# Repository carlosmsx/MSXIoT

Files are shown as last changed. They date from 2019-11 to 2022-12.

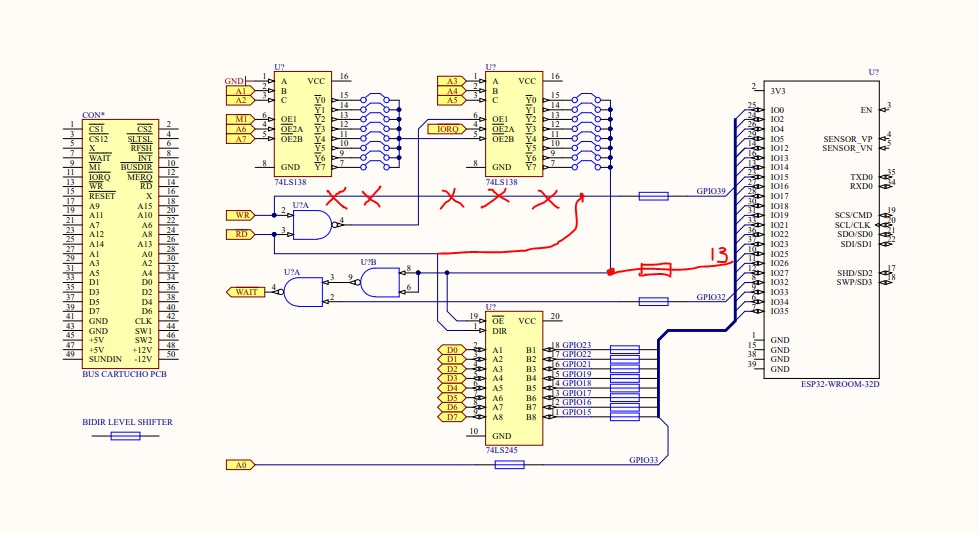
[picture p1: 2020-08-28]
doc/schema.jpg

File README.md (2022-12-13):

# MSX IoT

## Internet de las cosas para MSX
Si estás en este sitio probablemente ya sabes lo que es un MSX.
Pero, has oído hablar de Internet de las cosas (Internet of Things)?
Te presento MSX IoT.

Es un cartucho para MSX que permite IoT y algunos extras muy interesantes:

* Conectarse a redes WiFi
* Conectarse a dispositivos BT
* Conectarse a dispositivos seriales (TTL)
* Audio
* Disco en la nube
* Unidades de red

Una vez conectado a una red WiFi, las posibilidades son muchas. Por ejemplo, es posible comandar dispositivos a través de internet, o bien saber el estado de los mismos.

A nivel de hardware, MSX IoT consta de una ROM, un decodificador de direcciones y un módulo ESP32.

Cada vez que el Z80 accede para lectura o escritura a un puerto designado en el decodificador, se genera una señal WAIT hacia el Z80 y paralelamente se lanza una interrupción en el ESP32. Esto permite que en el microcontrolador se compruebe si la interrupción se debe a una operación de entrada o salida. Con esto el ESP32 puede leer bytes enviados por el Z80, o bien enviarlos a solicitud del mismo. Es decir, el microcontrolador trabaja en modo esclavo. De esta manera es posible establecer intercambio de datos controlados desde el Z80. 

## Otras posibles habilidades del cartucho

### Cloud disk
Para esto es necesario implementar una unidad de disco que permita acceder a un repositorio en la nube. Sería ideal si se pudiese conectar a por ejemplo google drive. 
Mapear una unidad de red a una carpeta compartida de windows o linux.
### Audio
El ESP32 tiene la posibilidad de generar audio a través de dos salidas que poseen un DAC. Sabiendo esto, el cartucho tiene previsto evolucionar sobre este punto de manera de conectar estas salidas a la entrada de audio de MSX. En teoría sería posible generar sonidos tan complejos como la programación del ESP32 lo permita.
### RS232 TTL
Se ha dejado disponible una UART en el cartucho de manera que el cartucho sirva como una interfaz serie. 
Sería necesario implementar las extensiones BASIC correspondientes
- CALL COMBREAK
- CALL COMDTR
- CALL COM GOSUB
- CALL COMHELP
- CALL COMINI
- CALL COMOFF
- CALL COMON
- CALL COMSTAT
- CALL COMSTOP
- CALL COMTERM

© Carlos Escobar 2019

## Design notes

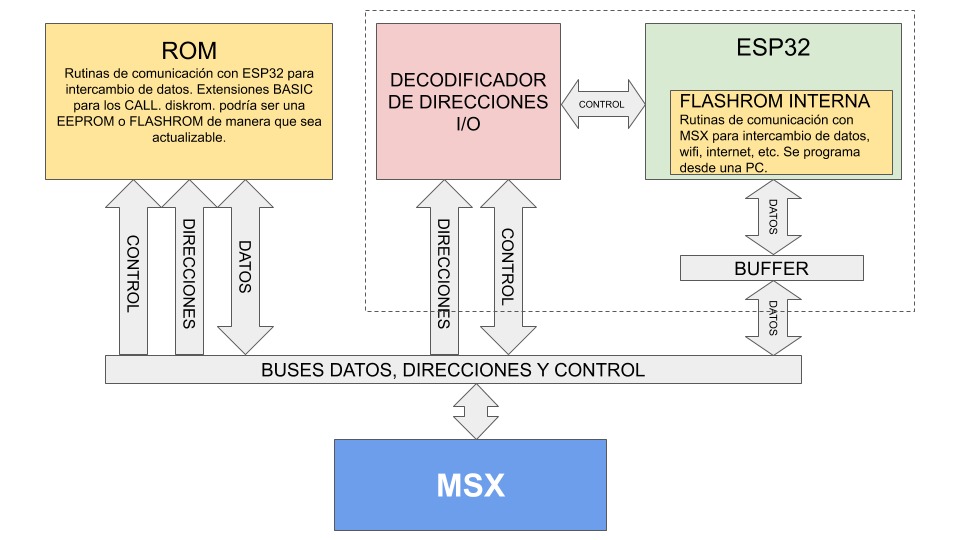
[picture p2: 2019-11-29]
doc/general.jpeg

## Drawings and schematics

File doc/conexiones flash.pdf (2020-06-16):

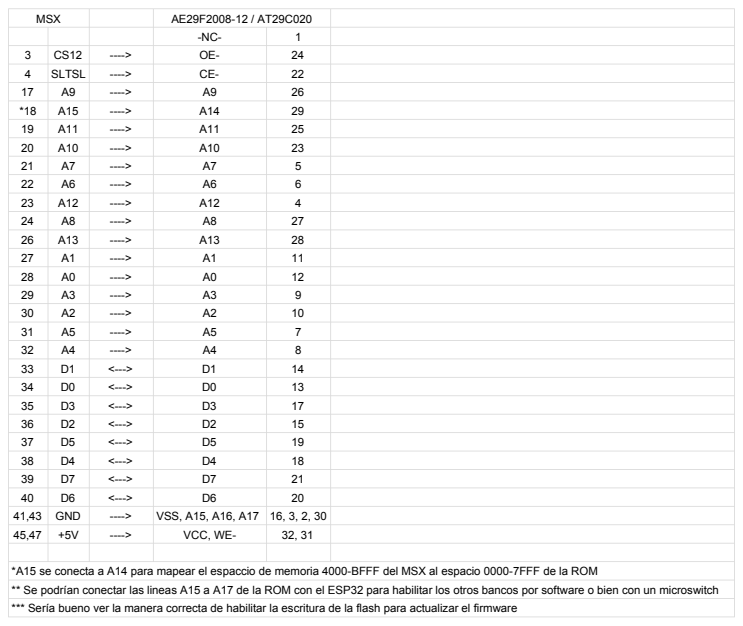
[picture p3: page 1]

*A15 se conecta a A14 para mapear el espaccio de memoria 4000-BFFF del MSX al espacio 0000-7FFF de la ROM
** Se podrían conectar las lineas A15 a A17 de la ROM con el ESP32 para habilitar los otros bancos por software o bien con un microswitch
*** Sería bueno ver la manera correcta de habilitar la escritura de la flash para actualizar el firmware

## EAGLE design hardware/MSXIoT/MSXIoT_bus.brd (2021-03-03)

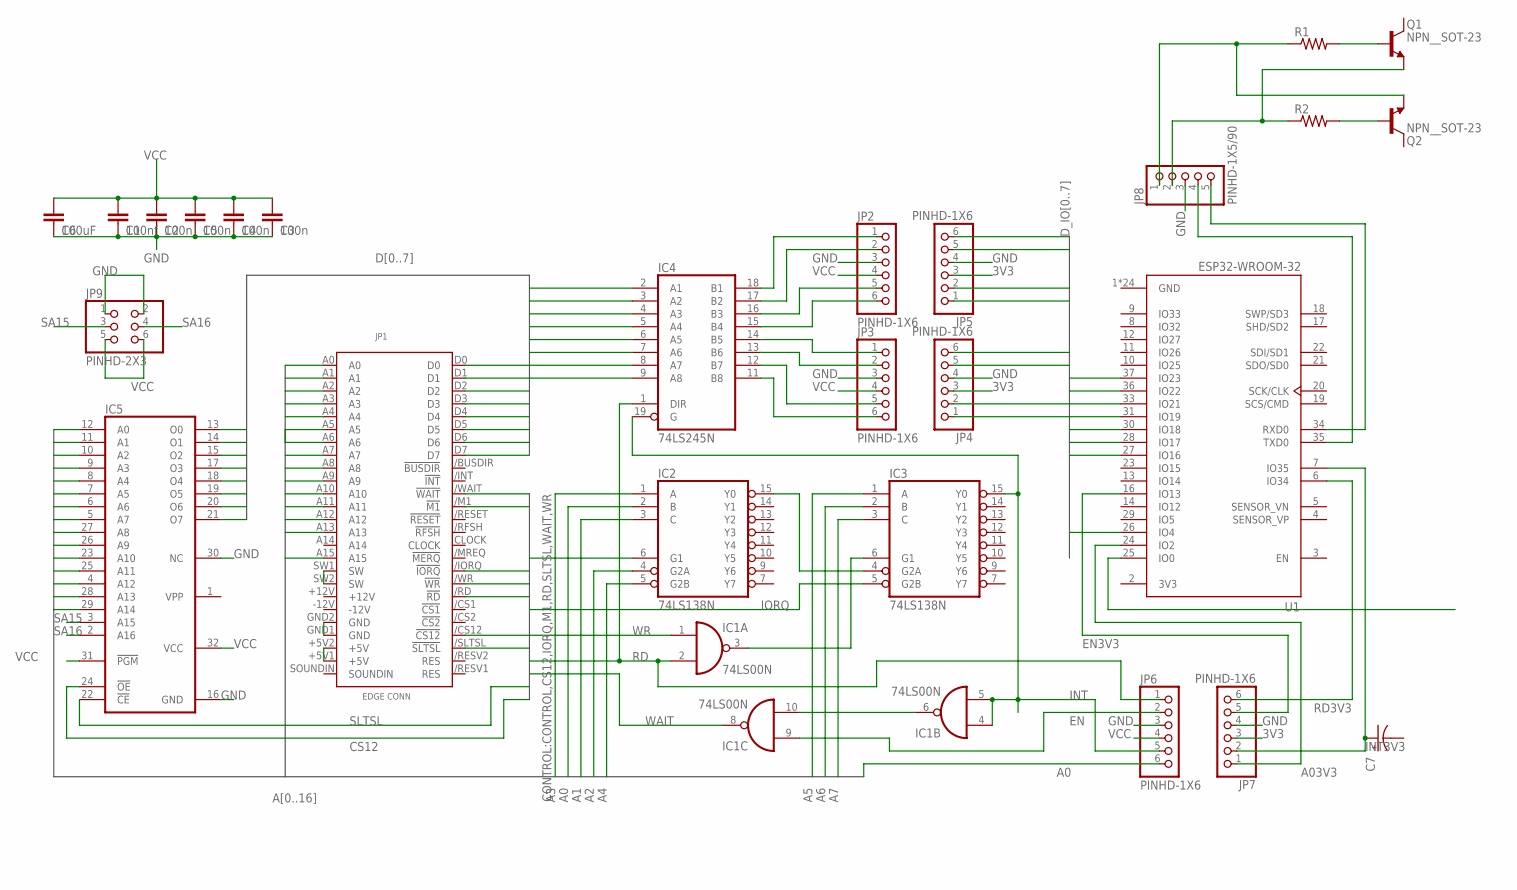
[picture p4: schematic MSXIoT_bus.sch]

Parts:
C1: 100nf; C2.5-2
C2, C3, C4, C5: 100n; C2.5-3
C6: 100uF; C2.5-6
C7: CPOL-US153CLV-0505; 153CLV-0505
IC1: 74LS00N; DIL14
IC2, IC3: 74LS138N; DIL16
IC4: 74LS245N; DIL20
IC5: 27C1001A; DIL32
JP1: MSXCART
JP2, JP3, JP4, JP5, JP6, JP7: PINHD-1X6; 1X06
JP8: PINHD-1X5/90; 1X05/90
JP9: PINHD-2X3; 2X03
Q1, Q2: NPN__SOT-23; SOT95P237X112-3N
R1, R2: R-US_0204/5; 0204/5
U1: ESP32-WROOM-32; MODULE_ESP32-WROOM-32

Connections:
3V3: JP4.3, JP5.3, JP7.3, U1.2 (3V3)
A0: IC2.2 (B), IC5.12 (A0), JP1.A0, JP6.6
A1: IC2.3 (C), IC5.11 (A1), JP1.A1
A2: IC2.4 (G2A), IC5.10 (A2), JP1.A2
A3: IC2.1 (A), IC5.9 (A3), JP1.A3
A03V3: JP7.1, U1.24 (IO2)
A4: IC2.5 (G2B), IC5.8 (A4), JP1.A4
A5: IC3.1 (A), IC5.7 (A5), JP1.A5
A6: IC3.2 (B), IC5.6 (A6), JP1.A6
A7: IC3.3 (C), IC5.5 (A7), JP1.A7
A8: IC5.27 (A8), JP1.A8
A9: IC5.26 (A9), JP1.A9
A10: IC5.23 (A10), JP1.A10
A11: IC5.25 (A11), JP1.A11
A12: IC5.4 (A12), JP1.A12
A13: IC5.28 (A13), JP1.A13
A14: IC5.29 (A14), JP1.A15
CS12: IC5.24 (!OE), JP1./CS12 (!CS12)
D0: IC4.2 (A1), IC5.13 (O0), JP1.D0
D1: IC4.3 (A2), IC5.14 (O1), JP1.D1
D2: IC4.4 (A3), IC5.15 (O2), JP1.D2
D3: IC4.5 (A4), IC5.17 (O3), JP1.D3
D4: IC4.6 (A5), IC5.18 (O4), JP1.D4
D5: IC4.7 (A6), IC5.19 (O5), JP1.D5
D6: IC4.8 (A7), IC5.20 (O6), JP1.D6
D7: IC4.9 (A8), IC5.21 (O7), JP1.D7
D_IO0: JP5.6, U1.37 (IO23)
D_IO1: JP5.5, U1.36 (IO22)
D_IO2: JP5.2, U1.33 (IO21)
D_IO3: JP5.1, U1.31 (IO19)
D_IO4: JP4.6, U1.30 (IO18)
D_IO5: JP4.5, U1.28 (IO17)
D_IO6: JP4.2, U1.27 (IO16)
D_IO7: JP4.1, U1.26 (IO4)
EN: IC1.9 (I0), JP6.2
EN3V3: JP7.5, U1.16 (IO13)
GND: C1.2, C2.2, C3.2, C4.2, C5.2, C6.2, IC1.7 (GND), IC2.8 (GND), IC3.8 (GND), IC4.10 (GND), IC5.16 (GND), IC5.30 (NC), JP1.GND1 (GND), JP1.GND2 (GND), JP2.3, JP3.3, JP4.4, JP5.4, JP6.3, JP7.4, JP8.3, JP9.1, JP9.2, U1.1 (GND), U1.15 (GND), U1.38 (GND), U1.39_1 (GND), U1.39_2 (GND), U1.39_3 (GND), U1.39_4 (GND), U1.39_5 (GND), U1.39_6 (GND), U1.39_7 (GND), U1.39_8 (GND), U1.39_9 (GND), U1.39_10 (GND), U1.39_11 (GND), U1.39_12 (GND), U1.39_13 (GND), U1.39_14 (GND), U1.39_15 (GND), U1.39_16 (GND), U1.39_17 (GND), U1.39_18 (GND), U1.39_19 (GND), U1.39_20 (GND), U1.39_21 (GND)
INT: IC1.4 (I0), IC1.5 (I1), IC3.15 (Y0), IC4.19 (G), JP6.5
INT3V3: C7.+, JP7.2, U1.7 (IO35)
IORQ: IC3.5 (G2B), JP1./IORQ (!IORQ)
M1: IC2.6 (G1), JP1./M1 (!M1)
unnamed: IC1.6 (O), IC1.10 (I1)
unnamed: IC4.18 (B1), JP2.1
unnamed: IC2.15 (Y0), IC3.4 (G2A)
unnamed: IC1.3 (O), IC3.6 (G1)
unnamed: IC4.17 (B2), JP2.2
unnamed: IC4.16 (B3), JP2.5
unnamed: IC4.15 (B4), JP2.6
unnamed: IC4.14 (B5), JP3.1
unnamed: IC4.13 (B6), JP3.2
unnamed: IC4.12 (B7), JP3.5
unnamed: IC4.11 (B8), JP3.6
unnamed: JP1.SW1 (SW), JP1.SW2 (SW)
unnamed: JP8.4, U1.35 (TXD0)
unnamed: JP8.5, U1.34 (RXD0)
unnamed: JP8.1, Q2.1 (E), R1.1
unnamed: Q1.2 (B), R1.2
unnamed: Q2.2 (B), R2.2
unnamed: JP8.2, Q1.1 (E), R2.1
RD: IC1.2 (I1), IC4.1 (DIR), JP1./RD (!RD), JP6.1
RD3V3: JP7.6, U1.6 (IO34)
SA15: IC5.3 (A15), JP9.3
SA16: IC5.2 (A16), JP9.4
SLTSL: IC5.22 (!CE), JP1./SLTSL (!SLTSL)
VCC: C1.1, C2.1, C3.1, C4.1, C5.1, C6.1, IC1.14 (VCC), IC2.16 (VCC), IC3.16 (VCC), IC4.20 (VCC), IC5.31 (!PGM), IC5.32 (VCC), JP1.+5V1 (+5V), JP1.+5V2 (+5V), JP2.4, JP3.4, JP6.4, JP9.5, JP9.6
WAIT: IC1.8 (O), JP1./WAIT (!WAIT)
WR: IC1.1 (I0), JP1./WR (!WR)

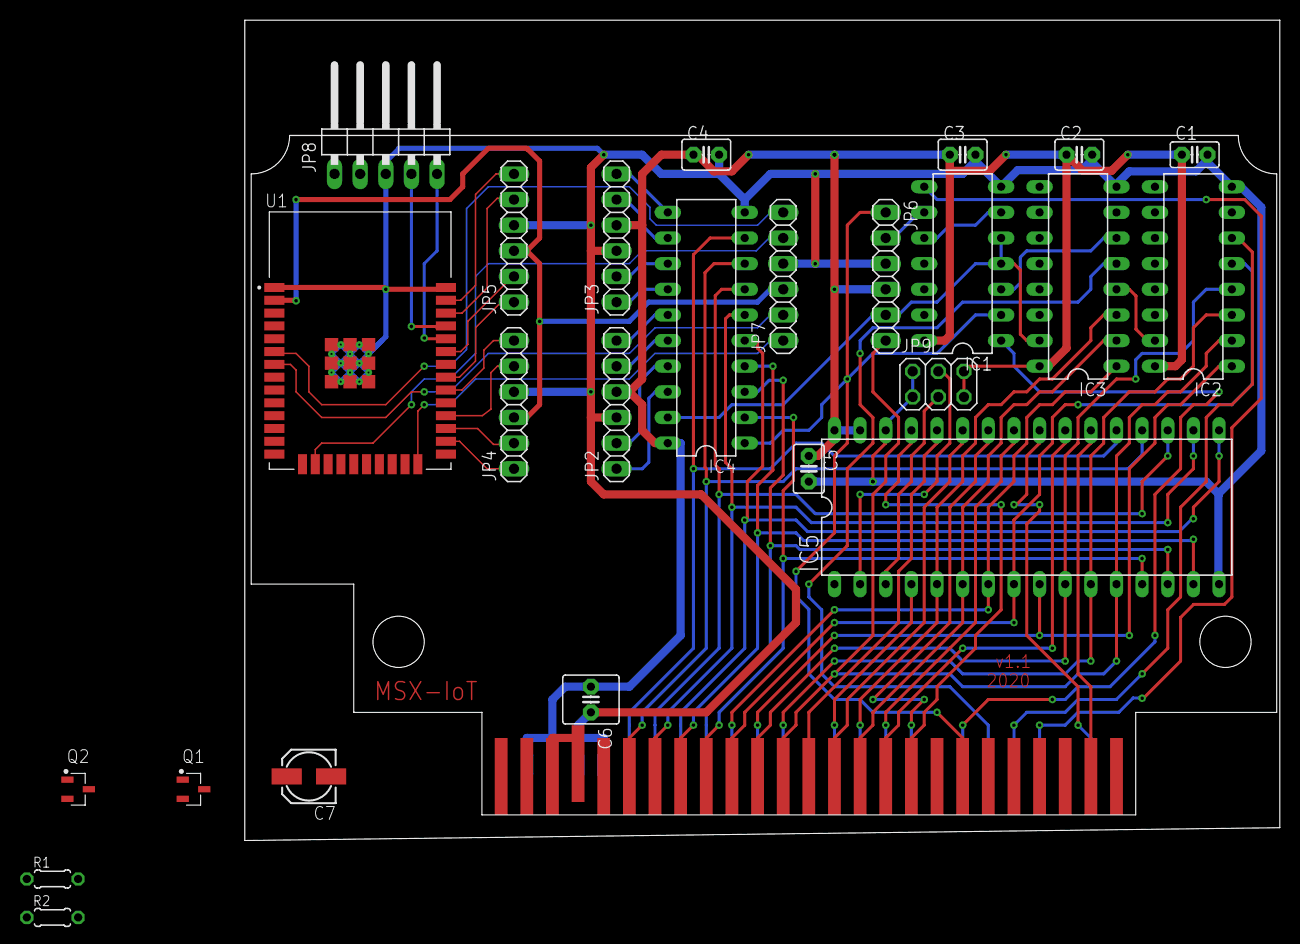
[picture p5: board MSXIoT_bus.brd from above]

Board: 2 copper layers, 102.5 x 81.3 mm, 26 parts (0 on the bottom side), 67 nets.

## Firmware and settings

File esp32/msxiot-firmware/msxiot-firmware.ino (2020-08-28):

/*
 * MSX INTERFACE DECO+ESP32
 * Autor: Carlos Escobar
 * 2019
 * 
 * Placa: ESP32 Dev Module
 * Partition Scheme: Huge APP (3MB No OTA/1MB SPIFFS)
 */
 
#include "BluetoothSerial.h" 
#include <WiFi.h>
#include <HTTPClient.h>
#include <string.h>
#include "SPIFFS.h"
#include "GDrive.h"

#define PIN_WAIT_EN 32
#define PIN_WAIT_ST 13
#define PIN_RD 39
#define PIN_A0 33
#define DATA_PINS {15,16,17,18,19,21,22,23} 

//32768+2
#define BUFSIZE 0x8002

#define CMD_NULL 0x00
#define CMD_SENDSTR 0x01
#define CMD_WLIST 0x10
#define CMD_WCLIST 0x11
#define CMD_WNET 0x12
#define CMD_WPASS 0x13
#define CMD_WCONN 0x14
#define CMD_WDISCON 0x15
#define CMD_WSTAT 0x16
#define CMD_WLOAD 0x17
#define CMD_WBLOAD 0x18
#define CMD_TCPSVR 0x19
#define CMD_TCPSEND 0x1A

#define CMD_FNAME 0x60
#define CMD_FSAVE 0x61
#define CMD_FLOAD 0x62
#define CMD_FFILES 0x63
#define CMD_LOADROM 0x64

#define CMD_CLOUDROM 0x70

#define CMD_GD_LST  0x80
#define CMD_GD_UPL  0x81
#define CMD_GD_DWL  0x82

static volatile uint16_t st_idx;
static volatile uint16_t st_size; //mantiene el tamaño del dato en el buffer
static volatile uint8_t st_cmd;   //indica el comando ejecutado

static volatile uint8_t st_status;
/*
  st_status: variable que indica el estado de la última operación
    7 6 5 4 3 2 1 0
    | | | | | | | \__ 
    | | | | | | \____
    | | | | | \______
    | | | | \________
    | | | \__________
    | | \____________
    | \______________ en alto indica que hay datos disponibles para leer desde el BUFFER (DATA_READY)
    \________________ en alto indica que la interfaz está ocupada (BUSY)
 */

#define BUSY 0x80
#define DATA_READY 0x40

char *st_buffer; //dynamically better
char *st_ssid = NULL;
char *st_password = NULL;
char st_server[64];
char st_file_name[64];
static volatile uint16_t st_server_port;

DRAM_ATTR const byte dmap[] = DATA_PINS;

/* Stores the handle of the task that will be notified when the
transmission is complete. */
static TaskHandle_t xTaskToNotify = NULL;

BluetoothSerial ESP_BT; //Object for Bluetooth

void IRAM_ATTR decoInt();
void IRAM_ATTR decoInt_old();

void IRAM_ATTR TaskISR( void * parameter) 
{
  uint32_t ulNotificationValue;

  while (true)
  {
    //waits for ISR notification
    ulNotificationValue = ulTaskNotifyTake( pdTRUE, portMAX_DELAY  );
    //st_counter2++;  
    if( ulNotificationValue == 1 )
    {
        /* The transmission ended as expected. */
        decoInt_old();
    }
  }
}

void setup() {
  Serial.begin(115200);
  
  if (!SPIFFS.begin(true)) {
    Serial.println("An Error has occurred while mounting SPIFFS");
    return;
  }

  /*
  File root = SPIFFS.open("/");
  File file = root.openNextFile();
  while(file){
      Serial.print("FILE: ");
      Serial.println(file.name());
      file = root.openNextFile();
  }
  file.close();
  */
  
  st_buffer = new char[BUFSIZE+2];

  ESP_BT.begin("MSX-IoT BT"); //Name of your Bluetooth Signal
  
  pinMode(PIN_WAIT_ST, INPUT_PULLUP);
  pinMode(PIN_RD, INPUT_PULLUP);
  pinMode(PIN_WAIT_EN, OUTPUT);
  pinMode(PIN_A0, INPUT_PULLUP);

  for (int i=0; i<8; i++)
    pinMode(dmap[i], INPUT);

  while (digitalRead(PIN_WAIT_ST)==LOW)
    digitalWrite(PIN_WAIT_EN, HIGH); //LOW);
  digitalWrite(PIN_WAIT_EN, LOW); //HIGH);

  String s = "MSX IoT 2019 corriendo en core "+String(xPortGetCoreID())+"\n";
  Serial.print(s);

  xTaskCreate(TaskISR, "decoInt", 1000, NULL, 10, &xTaskToNotify);
    
  attachInterrupt(digitalPinToInterrupt(PIN_WAIT_ST), decoInt, FALLING);
}

void IRAM_ATTR readData(uint8_t data)
{
  if (st_size<BUFSIZE) //<sizeof(_buffer))
  {
    st_buffer[st_size++]=data;
  }
  else
    st_status=0x01;
}

void IRAM_ATTR readCommand(uint8_t cmd)
{
  if (st_status & BUSY) 
    return;

  switch(cmd){
    case CMD_SENDSTR:
      st_idx = 0;
      st_size=0;
      st_status = DATA_READY;
      st_cmd = cmd;
      break;
    case CMD_WLIST:
    case CMD_WCLIST:
    case CMD_WCONN:
    case CMD_WDISCON:
    case CMD_WSTAT:
    case CMD_WNET: 
    case CMD_WPASS:
    case CMD_WLOAD:
    case CMD_WBLOAD:
    case CMD_TCPSVR:
    case CMD_TCPSEND:
    case CMD_FSAVE:
    case CMD_FLOAD:
    case CMD_FFILES:
    case CMD_FNAME:
    case CMD_LOADROM:
    case CMD_CLOUDROM:
    case CMD_GD_UPL:
      st_status = BUSY;
      st_cmd = cmd;
      break;
  }
}

void IRAM_ATTR receiveByte(int A0)
{
  uint8_t data=0;
  uint8_t bit=1;
  for (int i=0; i<8; i++)
  {
    if (digitalRead(dmap[i])==HIGH)
      data|=bit;
    bit=bit<<1; 
  }

  if (A0==0) 
    readData(data);
  else 
    readCommand(data);  

  while (digitalRead(PIN_WAIT_ST)==LOW)
    digitalWrite(PIN_WAIT_EN, HIGH); 
  digitalWrite(PIN_WAIT_EN, LOW);
}

uint8_t IRAM_ATTR writeData()
{
  if (st_status==DATA_READY && st_idx<st_size)
  {
    return st_buffer[st_idx++];
  }
  st_status=0;
  return 0;
}

void IRAM_ATTR dispatchByte(int A0)
{    
  uint8_t data=0;
  if (A0==0)
  {
    data=writeData();
  }
  else
  {
    data=st_status;
  }
  
  uint8_t bit=1;
  for (int i=0; i<8; i++)
  {
    pinMode(dmap[i], OUTPUT);
    digitalWrite(dmap[i], data&bit?HIGH:LOW);
    bit=bit<<1; 
  }

  delayMicroseconds(5);

  digitalWrite(PIN_WAIT_EN, HIGH);
  while (digitalRead(PIN_WAIT_ST)==LOW);
    digitalWrite(PIN_WAIT_EN, HIGH); 

  delayMicroseconds(5);

  //for (int i=0; i<8; i++)
  //  pinMode(dmap[i], INPUT);

  digitalWrite(PIN_WAIT_EN, LOW); 
}

void IRAM_ATTR decoInt_old()
{
  //st_counter3++;  
  int A0 = digitalRead(PIN_A0);
  int RD = digitalRead(PIN_RD);
  
  if (RD==HIGH) 
    receiveByte(A0);
  else
    dispatchByte(A0);
}

void IRAM_ATTR decoInt()
{
  //st_counter++;  
  BaseType_t xHigherPriorityTaskWoken = pdFALSE;
  vTaskNotifyGiveFromISR( xTaskToNotify, &xHigherPriorityTaskWoken );
  if (xHigherPriorityTaskWoken) 
    portYIELD_FROM_ISR( );
}

void getStrFromBuffer(char **s)
{
  char *p = *s;
  
  if (p != NULL)
    delete p;

  p = new char[st_size+1];
    
  for (st_idx=0; st_idx<st_size; st_idx++)
    p[st_idx] = st_buffer[st_idx];
  p[st_idx]='\0';

  Serial.println(p);
  *s=p;
}

void loop() {
  if (Serial.available()>0)
  {
    String s=Serial.readString();
    if (s=="dump")
    {
      for (uint16_t i=0; i<st_size; i++)
      {
        String s_hexa="";
        String s="";
        for(int j=0; j<32; j++, i++)
        {
          s_hexa=s_hexa+String(st_buffer[i],HEX)+" ";
          s=s+(st_buffer[i]>=32 && st_buffer[i]<128?String(st_buffer[i]):".");
        }
        Serial.println(s_hexa+s);    
      }
    }
    else
      st_status=(byte)atoi(s.c_str());
  }

  switch(st_cmd)
  {
    case CMD_WLIST:
    case CMD_WCLIST:
      {
        Serial.println("procesando comando "+String(st_cmd, HEX));
        int numSsid = WiFi.scanNetworks();
        
        if (numSsid == -1)
          st_size = sprintf(st_buffer, "WiFi net not found\r\n");
        else
        {
          st_size=0;
          for (int thisNet = 0; thisNet < numSsid; thisNet++) {
            if (st_cmd == CMD_WCLIST) 
              st_size += sprintf(&st_buffer[st_size], "_WNET(\"%s\")\r\n", WiFi.SSID(thisNet).c_str());
            else
              st_size += sprintf(&st_buffer[st_size], "%s\r\n", WiFi.SSID(thisNet).c_str());
          }
        }
        Serial.write((uint8_t*)st_buffer, st_size);
        st_cmd = 0;
        st_idx = 0;
        st_status = DATA_READY;
      }
      break;
    case CMD_WCONN:
      {
        if (st_ssid == NULL && st_password == NULL) 
        {
          st_size = sprintf(st_buffer, "first run _wnet(...) and _wpass(...)\r\n");
        }
        else if (st_ssid == NULL) 
        {
          st_size = sprintf(st_buffer, "first run _wnet(...)\r\n");
        }
        else if (st_password == NULL) 
        {
          st_size = sprintf(st_buffer, "first run _wpass(...)\r\n");
        }
        else
        {
          Serial.println("procesando comando "+String(st_cmd, HEX));
          WiFi.mode(WIFI_STA);
          WiFi.begin(st_ssid, st_password);
         
          //TODO: manejar máximo de reintentos para que no quede infinitamente
          uint8_t i = 0;
          while (WiFi.status() != WL_CONNECTED)
          {
            Serial.print('.');
            delay(500);
         
            if ((++i % 16) == 0)
            {
              Serial.println(F(" still trying to connect"));
            }
          }
          st_size = sprintf(st_buffer, "Connected to \"%s\"\r\nIP: %s\r\n", st_ssid, WiFi.localIP().toString().c_str());
          Serial.write((uint8_t*)st_buffer, st_size);
        }
        st_cmd = 0;
        st_idx = 0;
        st_status = DATA_READY;
      }
      break;
    case CMD_WDISCON:
      {
        WiFi.disconnect();
        st_size = sprintf(st_buffer, "disconnected\r\n");
        Serial.write((uint8_t*)st_buffer, st_size);
        st_cmd = 0;
        st_idx = 0;
        st_status = DATA_READY;
      }
      break;
    case CMD_WSTAT:
      {
        if (WiFi.status()==WL_CONNECTED)
          st_size = sprintf(st_buffer, "Connected to \"%s\"\r\nIP: %s\r\n", st_ssid, WiFi.localIP().toString().c_str());
        else
          st_size = sprintf(st_buffer, "Not connected\r\n");
        Serial.write((uint8_t*)st_buffer, st_size);
        st_cmd = 0;
        st_idx = 0;
        st_status = DATA_READY;
      }
      break;
    case CMD_WNET:
      /*
      for (st_idx=0; st_idx<st_size && st_idx<sizeof(st_ssid)-1; st_idx++)
        st_ssid[st_idx] = st_buffer[st_idx];
      st_ssid[st_idx]='\0';
      */
      getStrFromBuffer(&st_ssid);
      Serial.println("ssid="+String(st_ssid));
      st_cmd = 0;
      st_status=0;
      break;    
    case CMD_WPASS:
      /*
      for (st_idx=0; st_idx<st_size && st_idx<sizeof(st_password)-1; st_idx++)
        st_password[st_idx] = st_buffer[st_idx];
      st_password[st_idx]='\0';
      */
      getStrFromBuffer(&st_password);
      Serial.println("password="+String(st_password));
      st_cmd = 0;
      st_status=0;
      break;    
    case CMD_WLOAD:
      Serial.print("load=");
      for (int i=0; i<st_size; i++)
        Serial.print(String(st_buffer[i]));
      st_cmd = 0;
      st_status=0;
      break;    
    case CMD_WBLOAD:
      Serial.print("bload=");
      for (int i=0; i<st_size; i++)
        Serial.print(String(st_buffer[i]));
      st_cmd = 0;
      st_status=0;
      break;    
    case CMD_TCPSVR:
      st_buffer[st_size]='\0';
      strcpy(st_server, strtok(st_buffer, ":\0"));
      st_server_port=atoi(strtok(NULL, "\0"));
      Serial.println("server="+String(st_server)+":"+String(st_server_port));
      st_cmd = 0;
      st_status=0;
      break;    
    case CMD_TCPSEND:
      {
        WiFiClient client;
        if (client.connect(st_server, st_server_port)) {
          client.write(st_buffer, st_size);
          st_size = sprintf(st_buffer, "Sent Ok\r\n");
        }
        else
        {
          st_size = sprintf(st_buffer, "ERROR\r\n");
        }
        st_cmd = 0;
        st_idx = 0;
        st_status = DATA_READY;
      }
      break;
    case CMD_FNAME:
      for (st_idx=0; st_idx<st_size && st_idx<sizeof(st_file_name)-1; st_idx++)
        st_file_name[st_idx] = st_buffer[st_idx];
      st_file_name[st_idx]='\0';
      Serial.println("st_file_name="+String(st_file_name));
      st_cmd = 0;
      st_status=0;
      break;    
    case CMD_FSAVE:
      {
        Serial.println("FSAVE st_file_name="+String(st_file_name));
        String fname = "/"+String(st_file_name);
        File f = SPIFFS.open(fname.c_str(), "w");
        if (f) {
          f.write((uint8_t*)st_buffer, st_size);
          f.close();
        }
        st_cmd = 0;
        st_status=0;
      }
      break;    
    case CMD_FLOAD:
      {
        for (st_idx=0; st_idx<st_size && st_idx<sizeof(st_file_name)-1; st_idx++)
          st_file_name[st_idx] = st_buffer[st_idx];
        st_file_name[st_idx]='\0';
        Serial.println("FLOAD st_file_name="+String(st_file_name));
        String fname = "/"+String(st_file_name);
        File f = SPIFFS.open(fname.c_str(), "r");
        if (f) {
          st_size=f.size()+2;
          st_buffer[0]=(uint8_t)(st_size & 0xff);
          st_buffer[1]=(uint8_t)(st_size >> 8);
          Serial.println(String(f.size()));
          Serial.println(String(st_size));
          Serial.println(String((int)st_buffer[0]));
          Serial.println(String((int)st_buffer[1]));
          f.read((uint8_t*)(st_buffer+2), f.size());
          f.close();
        }
        st_idx=0;
        st_cmd = 0;
        st_status=DATA_READY;
      }
      break;    
    case CMD_LOADROM:
      {
        for (st_idx=0; st_idx<st_size && st_idx<sizeof(st_file_name)-1; st_idx++)
          st_file_name[st_idx] = st_buffer[st_idx];
        st_file_name[st_idx]='\0';
        //sprintf(st_file_name, "game.rom");
        Serial.println("FROM st_file_name="+String(st_file_name));
        String fname = "/"+String(st_file_name);
        File f = SPIFFS.open(fname.c_str(), "r");
        if (f) {
          st_size=f.size()+2;
          st_buffer[0]=(uint8_t)(st_size & 0xff);
          st_buffer[1]=(uint8_t)(st_size >> 8);
          Serial.println(String(f.size()));
          Serial.println(String(st_size));
          Serial.println(String((int)st_buffer[0]));
          Serial.println(String((int)st_buffer[1]));
          f.read((uint8_t*)(st_buffer+2), f.size());
          f.close();
        }
        st_idx=0;
        st_cmd = 0;
        st_status=DATA_READY;
      }
      break;    
    case CMD_FFILES:
      {
        File root = SPIFFS.open("/");
        File file = root.openNextFile();
        st_size=0;
       
        while(file){
          st_size += sprintf(&st_buffer[st_size], "%-13s\t%6i\r\n", file.name(), file.size());
          file = root.openNextFile();
        }
        file.close();

        Serial.write((uint8_t*)st_buffer, st_size);
        st_cmd = 0;
        st_idx = 0;
        st_status = DATA_READY;
      }
      break;
    case CMD_CLOUDROM:
      {
        //char st_url[128];
        //for (st_idx=0; st_idx<st_size && st_idx<sizeof(st_url)-1; st_idx++)
        //  st_url[st_idx] = st_buffer[st_idx];
        //st_url[st_idx]='\0';
        char *st_url=NULL;
        getStrFromBuffer(&st_url);

        String file_name=String(st_url).substring(String(st_url).lastIndexOf('/'));
        //Serial.println(st_url);
        HTTPClient http;
        File f = SPIFFS.open(file_name, "w");
        if (f) {
          http.begin(st_url);
          int httpCode = http.GET();
          if (httpCode > 0) 
          {
            if (httpCode == HTTP_CODE_OK) 
            {
              http.writeToStream(&f);
              st_size = sprintf(st_buffer, "Downloaded to \"%s\"\r\n", file_name.c_str());
            }
            else if (httpCode == 301) //redireccion
            {
              Serial.println("ups");
              st_size = sprintf(st_buffer, "HTTP GET redirect\r\n", httpCode);
            }
            else
            {
              Serial.printf("[HTTP] GET... failed, error: %s\r\n", http.errorToString(httpCode).c_str());
              st_size = sprintf(st_buffer, "HTTP GET error: %i\r\n", httpCode);
            }          
          } else 
          {
            Serial.printf("[HTTP] GET... failed, error: %s\r\n", http.errorToString(httpCode).c_str());
            st_size = sprintf(st_buffer, "HTTP GET error: %i\r\n", httpCode);
          }
          f.close();
        }
        else
        {
          st_size = sprintf(st_buffer, "Error openning file\r\n");
        }
        http.end();

        delete st_url;
        st_status = DATA_READY;
        st_cmd = 0;
        st_idx = 0;
      }
      break;
    case CMD_GD_UPL:
      {
        char *fileName = NULL;
        getStrFromBuffer(&fileName);

        String file_name= "/" + String(fileName);
        File f = SPIFFS.open(file_name.c_str(), "r");
        if (f) {
          st_size=f.size();
          f.read((uint8_t*)(st_buffer), f.size());
          f.close();
          if (upload(st_buffer, st_size, 10000))
            st_size = sprintf(st_buffer, "Upload Ok\r\n");
          else
            st_size = sprintf(st_buffer, "Upload Error\r\n");
        }
        else
        {
          st_size = sprintf(st_buffer, "Error openning file\r\n");
        }

        delete fileName;
        st_status = DATA_READY;
        st_cmd = 0;
        st_idx = 0;
      }
      break;
    case CMD_SENDSTR:
    case CMD_NULL:
      break;
    default:
      Serial.println("comando desconocido "+String(st_cmd));
  }
}

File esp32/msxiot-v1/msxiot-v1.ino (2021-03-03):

/*
 * MSX INTERFACE DECO+ESP32
 * Autor: Carlos Escobar
 * 2020
 * 
 * Placa: ESP32 Dev Module
 * Partition Scheme: Huge APP (3MB No OTA/1MB SPIFFS)
 */
 
#include "BluetoothSerial.h" 
#include <WiFi.h>
#include <HTTPClient.h>
#include <string.h>
#include "SPIFFS.h"
#include <freertos/FreeRTOS.h>
#include <freertos/task.h>
#include <freertos/task.h>
#include <driver/gpio.h>

#define PIN_WAIT_EN 32
#define PIN_WAIT_ST 13
#define PIN_RD 39
#define PIN_A0 33
#define D0 15
#define D1 16
#define D2 17
#define D3 18
#define D4 19
#define D5 21
#define D6 22
#define D7 23

#define DATA_MODE(x) pinMode(D0, x); pinMode(D1, x); pinMode(D2, x); pinMode(D3, x); pinMode(D4, x); pinMode(D5, x); pinMode(D6, x); pinMode(D7, x)
#define ARM_WAIT digitalWrite(PIN_WAIT_EN, LOW)
#define RELEASE_WAIT digitalWrite(PIN_WAIT_EN, HIGH)

#define READ_FROM_MSX(data) \
  if (digitalRead(D0)==HIGH) data =  0x01;\
  if (digitalRead(D1)==HIGH) data |= 0x02;\
  if (digitalRead(D2)==HIGH) data |= 0x04;\
  if (digitalRead(D3)==HIGH) data |= 0x08;\
  if (digitalRead(D4)==HIGH) data |= 0x10;\
  if (digitalRead(D5)==HIGH) data |= 0x20;\
  if (digitalRead(D6)==HIGH) data |= 0x40;\
  if (digitalRead(D7)==HIGH) data |= 0x80
  
#define WRITE_TO_MSX(data) \
  digitalWrite(D0, data&0x01?HIGH:LOW);\
  digitalWrite(D1, data&0x02?HIGH:LOW);\
  digitalWrite(D2, data&0x04?HIGH:LOW);\
  digitalWrite(D3, data&0x08?HIGH:LOW);\
  digitalWrite(D4, data&0x10?HIGH:LOW);\
  digitalWrite(D5, data&0x20?HIGH:LOW);\
  digitalWrite(D6, data&0x40?HIGH:LOW);\
  digitalWrite(D7, data&0x80?HIGH:LOW)

static uint16_t waitting_for_data = 0;
static uint8_t status_register = 0;
static uint8_t buf[512];

QueueHandle_t r_queue;
File dsk;

/* Stores the handle of the task that will be notified when pin ST change */
static TaskHandle_t xTaskToNotify = NULL;

BluetoothSerial ESP_BT; //Object for Bluetooth

/*
  st_status: variable que indica el estado de la última operación
    7 6 5 4 3 2 1 0
    | | | | | | | \__ 
    | | | | | | \____
    | | | | | \______
    | | | | \________
    | | | \__________
    | | \____________
    | \______________ en alto indica que hay datos disponibles para leer desde el BUFFER (DATA_READY)
    \________________ en alto indica que la interfaz está ocupada (BUSY)
 */

#define BUSY 0x80
#define DATA_READY 0x40


String hexByte(uint8_t b)
{
  return b>=16 ? String(b, HEX) : "0"+String(b, HEX);
}

void IRAM_ATTR decoISR(void)
{
  if (digitalRead(PIN_WAIT_ST)==HIGH) //released
  {
    ARM_WAIT;
  }
  else
  {
    int A0 = digitalRead(PIN_A0);
    if (digitalRead(PIN_RD)==HIGH) 
    {
      uint8_t data=0;
      READ_FROM_MSX(data);
      if (A0==0) 
        xQueueSend(r_queue, &data, portMAX_DELAY);
      //else 
      //  readCommand(data);  
      //RELEASE_WAIT;
    }
    else
    {
      if (A0==1)
      {
        status_register++;
        DATA_MODE(OUTPUT);
        WRITE_TO_MSX(status_register);    
        RELEASE_WAIT;
      }
      else
        waitting_for_data++;
    }
  }
}

void setup() {
  Serial.begin(115200);

  //ESP_BT.begin("MSX-IoT BT"); //Name of your Bluetooth Signal
  
  pinMode(PIN_WAIT_ST, INPUT_PULLUP);
  pinMode(PIN_RD, INPUT_PULLUP);
  pinMode(PIN_WAIT_EN, OUTPUT);
  pinMode(PIN_A0, INPUT_PULLUP);

  r_queue = xQueueCreate(512, sizeof(uint8_t));

  if (!SPIFFS.begin(true)) {
    Serial.println("An Error has occurred while mounting SPIFFS");
    return;
  }

  //dsk = SPIFFS.open("/4K.DSK", "r+");

  Serial.print("MSX IoT 2020 corriendo en core "+String(xPortGetCoreID())+"\n");

  attachInterrupt(digitalPinToInterrupt(PIN_WAIT_ST), decoISR, CHANGE);
  DATA_MODE(INPUT);
  RELEASE_WAIT;
  ARM_WAIT;
}


uint8_t state=0;
uint8_t drive_number;
uint8_t n_sectors;
uint8_t media;
uint16_t address;
uint16_t idx;

void loop() {
  uint8_t data;

  switch(state)
  {
    case 0:
      xQueueReceive(r_queue, &data, portMAX_DELAY);
      if (data==0xF0)
        state = 10;
      else if (data==0xF1)
        state = 20;
      else
        Serial.print(char(data));
      RELEASE_WAIT;
      break;
    case 10:
      xQueueReceive(r_queue, &data, portMAX_DELAY);
      drive_number = data;
      state = 11;
      RELEASE_WAIT;
      break;
    case 11:
      xQueueReceive(r_queue, &data, portMAX_DELAY);
      n_sectors = data;
      state = 12;
      RELEASE_WAIT;
      break;
    case 12:
      xQueueReceive(r_queue, &data, portMAX_DELAY);
      media = data;
      state = 13;
      RELEASE_WAIT;
      break;
    case 13: 
      xQueueReceive(r_queue, &data, portMAX_DELAY);
      address = data<<8;
      state = 14;
      RELEASE_WAIT;
      break;
    case 14:
      xQueueReceive(r_queue, &data, portMAX_DELAY);
      address |= data;
      idx = 0;
      Serial.println("WR drive="+String(drive_number)+" n_sec="+String(n_sectors)+" med="+String(media,HEX)+" addr="+String(address));
      dsk = SPIFFS.open("/4K.DSK", "r+");
      state = 15;
      RELEASE_WAIT;
      break;
    case 15:
      xQueueReceive(r_queue, &buf[idx], portMAX_DELAY);
      idx++;
      if (idx == 512)
      {
        dsk.seek(address * 512, SeekSet);
        dsk.write(buf, 512);
        idx = 0;
        address++;
        n_sectors--;  
        if (n_sectors == 0)
        {
          dsk.close();
          state = 0;
        }
      }
      RELEASE_WAIT;
      break;
    case 20:
      xQueueReceive(r_queue, &data, portMAX_DELAY);
      drive_number = data;
      state = 21;
      RELEASE_WAIT;
      break;
    case 21:
      xQueueReceive(r_queue, &data, portMAX_DELAY);
      n_sectors = data;
      state = 22;
      RELEASE_WAIT;
      break;
    case 22:
      xQueueReceive(r_queue, &data, portMAX_DELAY);
      media = data;
      state = 23;
      RELEASE_WAIT;
      break;
    case 23: 
      xQueueReceive(r_queue, &data, portMAX_DELAY);
      address = data<<8;
      state = 24;
      RELEASE_WAIT;
      break;
    case 24:
      xQueueReceive(r_queue, &data, portMAX_DELAY);
      address |= data;
      idx = 0;
      Serial.println("RD drive="+String(drive_number)+" n_sec="+String(n_sectors)+" med="+String(media,HEX)+" addr="+String(address));
      dsk = SPIFFS.open("/4K.DSK", FILE_READ);
      dsk.seek(address * 512, SeekSet);
      dsk.read(buf, 512);
      state = 25;
      RELEASE_WAIT;
      break;
    case 25:
      if (waitting_for_data > 0)
      {
        DATA_MODE(OUTPUT);
        WRITE_TO_MSX(buf[idx]);    

        waitting_for_data--;
        idx++;
        if (idx == 512)
        {
          address++;
          n_sectors--;  
          if (n_sectors == 0)
          {
            state = 0;
            dsk.close();
          }
          else
          { 
            dsk.seek(address * 512, SeekSet);
            dsk.read(buf, 512);
            idx = 0;
          }
        }
        RELEASE_WAIT;
      }
      break;
  }
}

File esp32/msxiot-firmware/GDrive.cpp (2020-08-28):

#include <Arduino.h>
#include <WiFiClient.h>
#include <WiFiClientSecure.h>
#include "Base64.h"
#include "GDrive.h"



//https://script.google.com/macros/s/AKfycbwjsvWX76H9KCeHyztjTUMyHpqagN_5wi2_Lqj2wFfGxEZwX_U/exec

const char* myDomain = "script.google.com";
String myScript = "/macros/s/AKfycbwjsvWX76H9KCeHyztjTUMyHpqagN_5wi2_Lqj2wFfGxEZwX_U/exec";
//String myScript = "/macros/s/XXXXXXXXXXXXXXXXXXXXXX/exec";    //Replace with your own url
String myFilename = "filename=test.jpg";
String mimeType = "&mimetype=image/jpeg";
String myImage = "&data=";

/*
const char* test_root_ca= \
     "-----BEGIN CERTIFICATE-----\n" \
     "MIIEkjCCA3qgAwIBAgIQCgFBQgAAAVOFc2oLheynCDANBgkqhkiG9w0BAQsFADA/\n" \
     "MSQwIgYDVQQKExtEaWdpdGFsIFNpZ25hdHVyZSBUcnVzdCBDby4xFzAVBgNVBAMT\n" \
     "DkRTVCBSb290IENBIFgzMB4XDTE2MDMxNzE2NDA0NloXDTIxMDMxNzE2NDA0Nlow\n" \
     "SjELMAkGA1UEBhMCVVMxFjAUBgNVBAoTDUxldCdzIEVuY3J5cHQxIzAhBgNVBAMT\n" \
     "GkxldCdzIEVuY3J5cHQgQXV0aG9yaXR5IFgzMIIBIjANBgkqhkiG9w0BAQEFAAOC\n" \
     "AQ8AMIIBCgKCAQEAnNMM8FrlLke3cl03g7NoYzDq1zUmGSXhvb418XCSL7e4S0EF\n" \
     "q6meNQhY7LEqxGiHC6PjdeTm86dicbp5gWAf15Gan/PQeGdxyGkOlZHP/uaZ6WA8\n" \
     "SMx+yk13EiSdRxta67nsHjcAHJyse6cF6s5K671B5TaYucv9bTyWaN8jKkKQDIZ0\n" \
     "Z8h/pZq4UmEUEz9l6YKHy9v6Dlb2honzhT+Xhq+w3Brvaw2VFn3EK6BlspkENnWA\n" \
     "a6xK8xuQSXgvopZPKiAlKQTGdMDQMc2PMTiVFrqoM7hD8bEfwzB/onkxEz0tNvjj\n" \
     "/PIzark5McWvxI0NHWQWM6r6hCm21AvA2H3DkwIDAQABo4IBfTCCAXkwEgYDVR0T\n" \
     "AQH/BAgwBgEB/wIBADAOBgNVHQ8BAf8EBAMCAYYwfwYIKwYBBQUHAQEEczBxMDIG\n" \
     "CCsGAQUFBzABhiZodHRwOi8vaXNyZy50cnVzdGlkLm9jc3AuaWRlbnRydXN0LmNv\n" \
     "bTA7BggrBgEFBQcwAoYvaHR0cDovL2FwcHMuaWRlbnRydXN0LmNvbS9yb290cy9k\n" \
     "c3Ryb290Y2F4My5wN2MwHwYDVR0jBBgwFoAUxKexpHsscfrb4UuQdf/EFWCFiRAw\n" \
     "VAYDVR0gBE0wSzAIBgZngQwBAgEwPwYLKwYBBAGC3xMBAQEwMDAuBggrBgEFBQcC\n" \
     "ARYiaHR0cDovL2Nwcy5yb290LXgxLmxldHNlbmNyeXB0Lm9yZzA8BgNVHR8ENTAz\n" \
     "MDGgL6AthitodHRwOi8vY3JsLmlkZW50cnVzdC5jb20vRFNUUk9PVENBWDNDUkwu\n" \
     "Y3JsMB0GA1UdDgQWBBSoSmpjBH3duubRObemRWXv86jsoTANBgkqhkiG9w0BAQsF\n" \
     "AAOCAQEA3TPXEfNjWDjdGBX7CVW+dla5cEilaUcne8IkCJLxWh9KEik3JHRRHGJo\n" \
     "uM2VcGfl96S8TihRzZvoroed6ti6WqEBmtzw3Wodatg+VyOeph4EYpr/1wXKtx8/\n" \
     "wApIvJSwtmVi4MFU5aMqrSDE6ea73Mj2tcMyo5jMd6jmeWUHK8so/joWUoHOUgwu\n" \
     "X4Po1QYz+3dszkDqMp4fklxBwXRsW10KXzPMTZ+sOPAveyxindmjkW8lGy+QsRlG\n" \
     "PfZ+G6Z6h7mjem0Y+iWlkYcV4PIWL1iwBi8saCbGS5jN2p8M+X+Q7UNKEkROb3N6\n" \
     "KOqkqm57TH2H3eDJAkSnh6/DNFu0Qg==\n" \
     "-----END CERTIFICATE-----\n";
*/
/*
void setup()
{
  WRITE_PERI_REG(RTC_CNTL_BROWN_OUT_REG, 0);
  
  Serial.begin(115200);
  delay(10);
}
*/
//https://github.com/zenmanenergy/ESP8266-Arduino-Examples/
String urlencode(String str)
{
    String encodedString="";
    char c;
    char code0;
    char code1;
    char code2;
    for (int i =0; i < str.length(); i++){
      c=str.charAt(i);
      if (c == ' '){
        encodedString+= '+';
      } else if (isalnum(c)){
        encodedString+=c;
      } else{
        code1=(c & 0xf)+'0';
        if ((c & 0xf) >9){
            code1=(c & 0xf) - 10 + 'A';
        }
        c=(c>>4)&0xf;
        code0=c+'0';
        if (c > 9){
            code0=c - 10 + 'A';
        }
        code2='\0';
        encodedString+='%';
        encodedString+=code0;
        encodedString+=code1;
        //encodedString+=code2;
      }
      yield();
    }
    return encodedString;
}

//código modificado tomado de https://github.com/gsampallo/esp32cam-gdrive/blob/master/esp32cam-gdrive.ino
bool upload(char *input, uint16_t fb_len, uint16_t waitingTime) {
  bool result = false;
  Serial.println("Connect to " + String(myDomain));
  WiFiClientSecure client;
  //WiFiClient client;
  //client.setCACert(test_root_ca);
  
  if (client.connect(myDomain, 443)) {
    Serial.println("Connection successful");
    
    char output[base64_enc_len(3)];
    String imageFile = "";
    for (int i=0;i<fb_len;i++) {
      base64_encode(output, (input++), 3);
      if (i%3==0) imageFile += urlencode(String(output));
    }
    String Data = myFilename+mimeType+myImage;
    
    Serial.println("POST " + myScript + " HTTP/1.1");
    Serial.println("Host: " + String(myDomain));
    Serial.println("Content-Length: " + String(Data.length()+imageFile.length()));
    Serial.println("Content-Type: application/x-www-form-urlencoded");
    Serial.println();
    Serial.println(Data);

    
    client.println("POST " + myScript + " HTTP/1.1");
    client.println("Host: " + String(myDomain));
    client.println("Content-Length: " + String(Data.length()+imageFile.length()));
    client.println("Content-Type: application/x-www-form-urlencoded");
    client.println();
    client.print(Data);
    int Index;
    for (Index = 0; Index < imageFile.length(); Index = Index+1000) {
      client.print(imageFile.substring(Index, Index+1000));
      Serial.println(imageFile.substring(Index, Index+1000));
    }
    
    Serial.println("Waiting for response.");
    long int StartTime=millis();
    while (!client.available()) {
      Serial.print(".");
      delay(100);
      if ((StartTime+waitingTime) < millis()) {
        Serial.println();
        Serial.println("No response.");
        //If you have no response, maybe need a greater value of waitingTime
        break;
      }
    }
    Serial.println();   
    while (client.available()) {
      Serial.print(char(client.read()));
    }
    result = true;  
  } else {         
    Serial.println("Connected to " + String(myDomain) + " failed.");
  }
  client.stop();
  return result;
}

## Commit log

2019-11-28 codigo de prueba
2019-11-29 agregadas demoras a los puntos de I/O
2019-11-30 antes de implementar nuevos comandos
2019-12-04 primera version con que se conecta y toma IP
2020-02-26 reserva memoria en el workarea
2020-03-08 Agregada rutina en 8000H, y carga un archivo rom de prueba pero solo lo muestra por pantalla. Hay que implementar la rutina de swap a RAM y cargar directamente ahi.
    [msxiot-firmware.ino]
2020-03-12 primera version que carga una ROM en memoria y la ejecuta correctamente.
2020-03-23 FFILES ahora lista tamaño. LOADROM carga ROMs de 16K y 32K. Todavía hay que probar bien la carga de 32K
2020-03-28 -Mejoras en el código en general. -Validación de errores para CLOUDROM. -agregada entrada GETLOG1 para evitar correr dos veces un comando (TCPSEND y CLOUDROM)
    [msxiot-firmware.ino]
2020-06-16 info sobre cómo conectar la memoria flash. sirve para ROMS de 32K
2020-08-28 soporte para gdrive
2020-10-09 herramientas utiles basadas en arduino
2020-10-21 Prototipo de diskrom
2020-11-11 primera subida de firmware con soporte para MSXDOS
2020-11-22 primera subida:
    [MSXIoT.brd, MSXIoT.sch, MSXIoT_bus.brd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]
2021-08-12 DEFDPB error found and fixed
    [firmware_bridge_avr.ino, msxiot_firmware.h, testing_uart.ino]
